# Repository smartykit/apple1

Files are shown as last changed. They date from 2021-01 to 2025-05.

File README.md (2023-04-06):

# SmartyKit One Apple-1 compatible computer repo structure

SmartyKit One Apple-1 compatible computer's drivers and software (http://www.smartykit.io/):
* **Controllers drivers** – drivers for all used controllers (Video, Keyboard & Hi-Res Video)
    - *Keyboard driver* uses Arduino PS2KeyAdvanced library.
    - *Video driver* uses Arduino custom 2.8" TFT screen driver (based on Adafruit driver) and TV Terminal library.
    - *Hi-Res Video driver* uses library written by Grant Searle and Dave Curran
* **Garage ASCII art** – beautiful Steve Job's garage ASCII art by Adel Faure

* **ROM** – ROM chip firmwarwe source code (6502 assembler) & development configs (Makefile to build your own version of ROM using `ca65` 6502 assembler & config files to run the code in POM1 emulator)

* **POM1 software emulator** – Apple-1 software emulator by Verhille Arnaud to test SmartyKit ROM code before burning firmare 

SmartyKit 1 assembly

# Highlights

## SmartyKit One's loading splash screen ASCII art
Steve Job's garage ASCII art by Adel Faure:

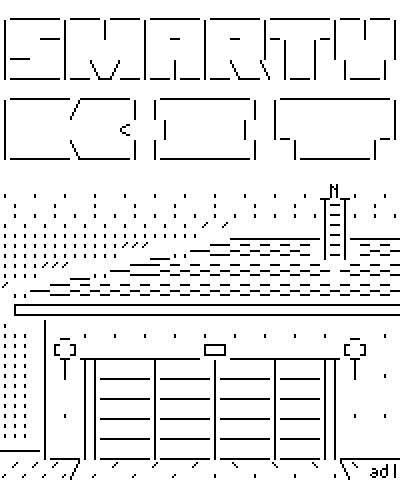
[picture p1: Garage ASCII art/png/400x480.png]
Steve Job's Garage


## SmartyKit One's ROM to run on POM1 Software Emulator 
POM 1 cross-platform emulator by Verhille Arnaud to test SmartyKit One ROM with software.

Video to-do (https://youtu.be/rniZDdS6toI)

## SmartyKit One's ROM development console
Easy-to-use development tool to write your own software for SmartyKLit One (you need just run make in your Terminal) and learn how ROM is organized.

Here is an example:
```bash
SERGEYs-MacBook:ROM_development spanarin$ make
SmartyKit 1: 6502 assembler & C-compiler to ROM (.bin)
Assembling and linking...
ca65 -l ROM_listing.asm SmartyKit1_ROM.asm
ld65 -m ROM.map -o SmartyKit1_ROM.bin SmartyKit1_ROM.o -C apple1.cfg
ld65 -o SmartyKit1_ROM_symon.bin SmartyKit1_ROM.o -C symon.cfg
SERGEYs-MacBook:ROM_development spanarin$
```

## SmartyKit One's 8x8 Pixel Art online tool for program at $FC00 in ROM (FC00R command)
You could draw your own pixel art using our online tool (https://smartykit.github.io/pixelart-project/), get the code for this image and load this code it to SmartyKit (or emulator) memory using command:
```
1111: 3C 42 A5 81 A5 99 42 3C (Return)
FC00R (Return)
```

## SmartyKit One's plates for breadboards

PCB version (black) and Wooden version (file for wood laser cutter: [download](https://github.com/smartykit/apple1/blob/01ea2ec54a94a7a31ee613f007602f0c08cb13ae/SmartyKit-Plate-for-breadboards(laser-cut).cdr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))

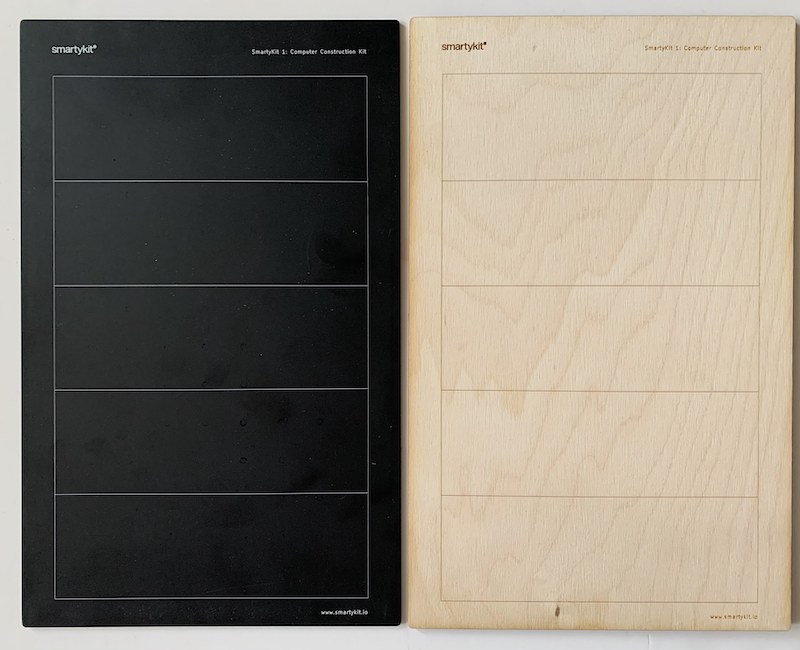
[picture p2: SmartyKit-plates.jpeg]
SmartyKit Plates


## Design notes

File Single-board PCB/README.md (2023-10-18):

# SmartyKit One, Apple-1 compatible computer's Single-board PCB gerbers

SmartyKit One (http://www.smartykit.io/), Apple-1 compatible computer's PCB production files:
* Gerbers with SMD (LED) pick&place files
* Schematics
* Assembly Drawing
* 3D Preview

These particular files were successfully used with JLCPCB.

This board is quite popular having almost 1 million views on TikTok: https://vt.tiktok.com/ZSN6fEfT1/

Short demo on how it works: https://youtube.com/shorts/yasQL7dERKI?si=belrGXeBrC0KbUY7

Then you can decorate your office or WFH study in a geeky way: https://www.instagram.com/p/CnwZLHJIJ2m/?igshid=MzRlODBiNWFlZA==

SmartyKit Discord community could be helpful during the build. 

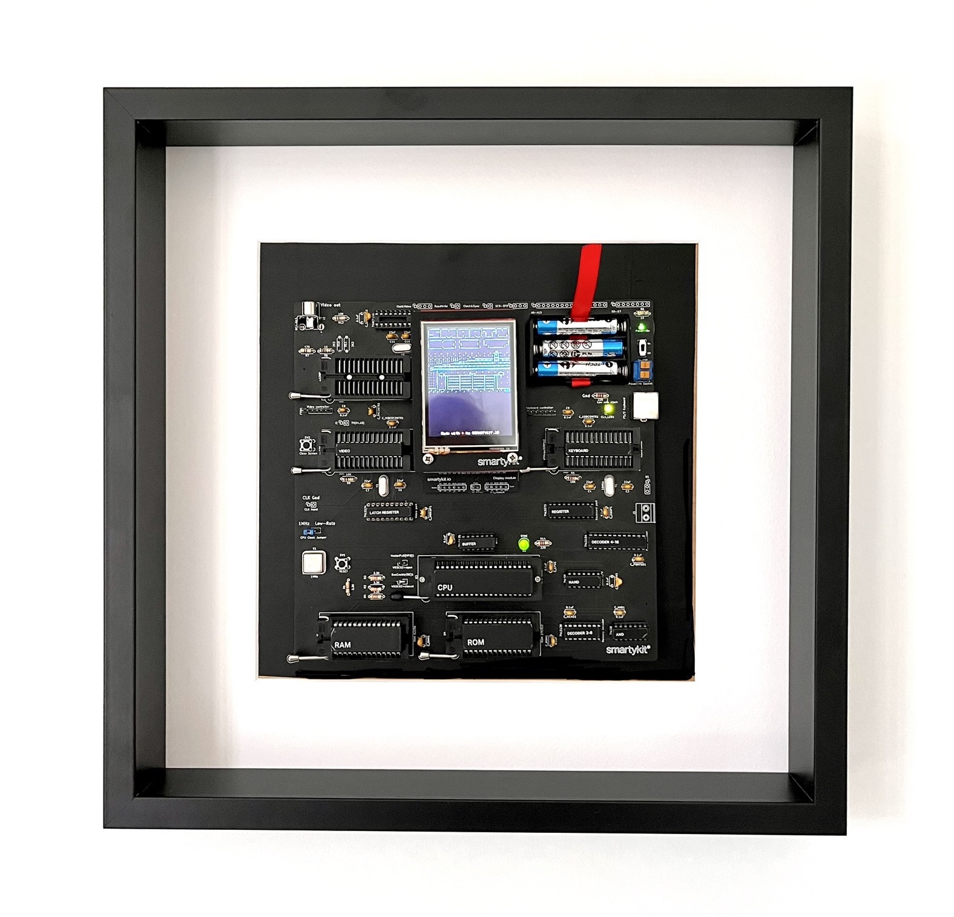
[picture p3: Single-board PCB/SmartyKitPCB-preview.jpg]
SmartyKit One PCB Preview


## Video instruction on ordering from JLCPCB

Watch video instruction on ordering from JLCPCB (https://www.youtube.com/watch?v=eLBNkHj5aZs)

## LED part number

For Power-On LED in 0603 package used – Everlight Elec, Part# 19-217/GHC-YR1S2/3T.

[JLCPCB Part# C72043](https://jlcpcb.com/partdetail/EverlightElec-19_217_GHC_YR1S23T/C72043)

## Questions?

You could contact Sergey (sergey@smartykit.io) or reach us on X (Twitter) ([@SmartyKitE](https://www.twitter.com/SmartyKitE)).

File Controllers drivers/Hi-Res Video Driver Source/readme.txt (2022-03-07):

To use this library you need an additional ATMega328P to act as a video processor, and a 74HCT166 shift register to generate the video bit stream.

The video processor hex file needs to be programmed into an ATMega328P with the following fuses set:
E6 D9 FF

In avrdude that is: (change the com port as appropriate)

avrdude -P COM3 -b 19200 -c avrisp -p m328p -n
avrdude -P COM3 -b 19200 -c avrisp -p m328p -U lfuse:w:0xe6:m
avrdude -P COM3 -b 19200 -c avrisp -p m328p -U hfuse:w:0xd9:m
avrdude -P COM3 -b 19200 -c avrisp -p m328p -U efuse:w:0xff:m
avrdude -P COM3 -b 19200 -c avrisp -p m328p -U flash:w:SBCVideo.hex

The video processor code is written by Grant Searle, based on code by Daryl Rictor.

Their pages are as follows:

http://searle.x10host.com/MonitorKeyboard/index.html
http://sbc.rictor.org/vid3.html

80x25 Terminal library by Dave Curran, based on code from the above. For more info see:

http://blog.tynemouthsoftware.co.uk/2013/09/arduino-80x25-tv-video-output-library.html
http://blog.tynemouthsoftware.co.uk/2013/09/arduino-80x25-tv-video-output-library_15.html

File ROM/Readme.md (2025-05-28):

## SmartyKit 1 Memory Map – ROM and RAM

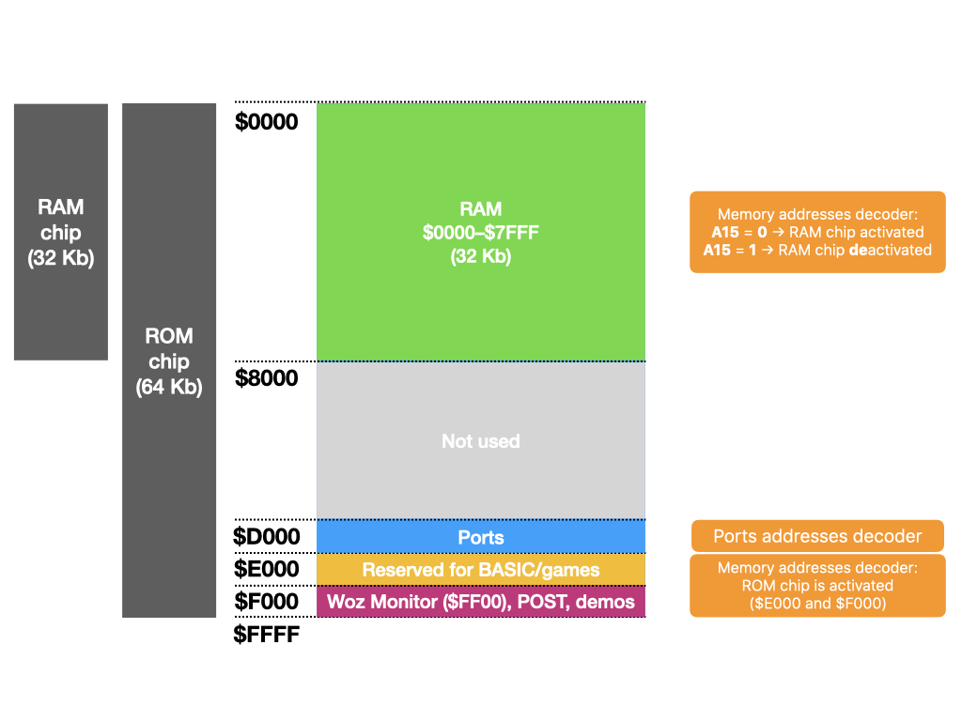
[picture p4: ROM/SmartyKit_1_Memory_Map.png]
SmartyKit 1 Memory Map


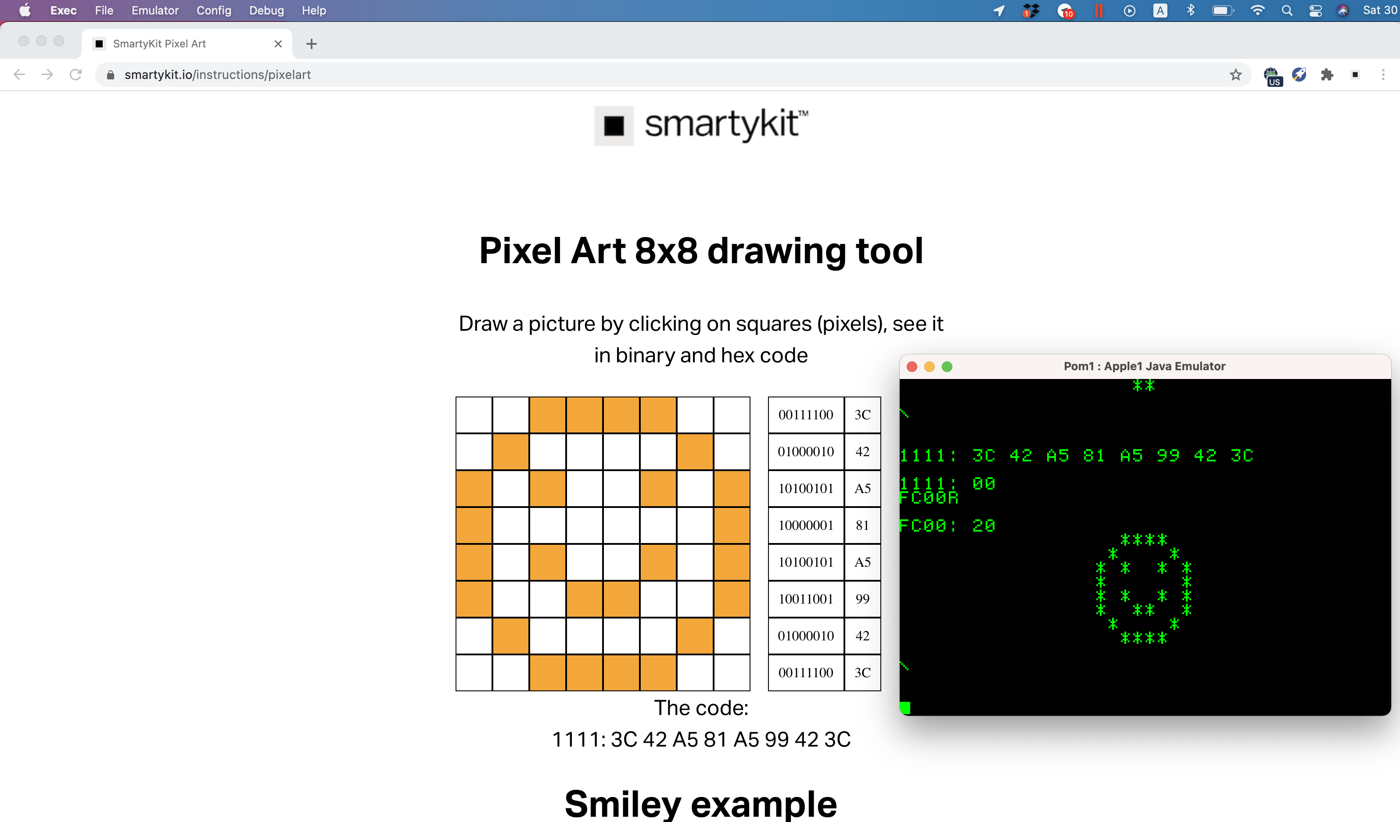
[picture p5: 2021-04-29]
SmartyKit Pixel Art example.png

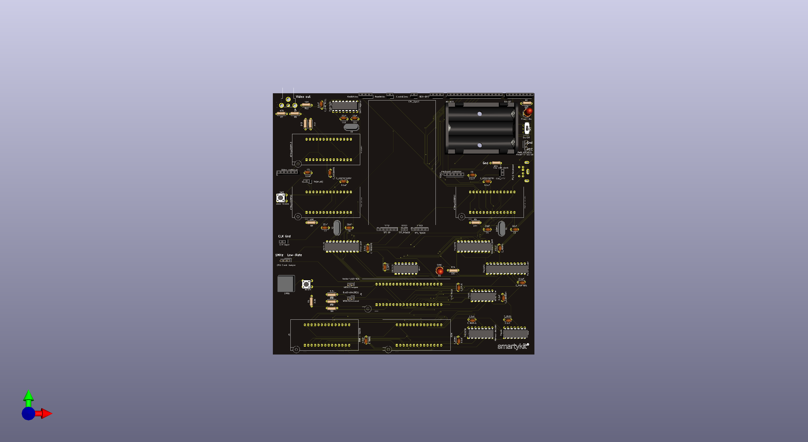
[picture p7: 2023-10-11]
Single-board PCB/SmartyKitPCB-3D-preview.png

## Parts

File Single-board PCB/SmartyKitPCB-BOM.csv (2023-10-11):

Comment | Designator | Footprint | LCSC Part #
NAND R/W quad 2-input NAND gate | 74LS0 | DIP-14_W7.62mm
AND Quad And2 | 74LS8 | DIP-14_W7.62mm
BIT7 Quad buffer 3-State outputs | 74LS125 | DIP-14_W7.62mm
Memory decoder Decoder 3 to 8 active low outputs | 74LS138 | DIP-16_W7.62mm
Ports decoder Decoder 4 to 16 | 74LS154 | DIP-24_W7.62mm
Keyboard port 8-bit Latch 3-state outputs | 74LS573 | DIP-20_W7.62mm
Video port 8-bit Register, 3-state outputs | 74LS574 | DIP-20_W7.62mm
A0-A15 Generic connector, single row, 01x16, script generated (kicad-library-utils/schlib/autogen/connector/) | AddressBus1 | PinSocket_1x16_P2.54mm_Vertical
5V Multiple-cell battery | BT1 | BatteryHolder_Keystone_2479_3xAAA
W65C02=closed Jumper, 2-pole, closed/bridged | BusEnable(BE)1 | PinHeader_1x02_P2.54mm_Vertical
0.1uF Unpolarized capacitor, small symbol | C1,C2,C5,C8,C9,C12,C13,C14,C15,C16,C17,C18,C19,C20,C21,C22 | C_Disc_D5.0mm_W2.5mm_P5.00mm
22pF Unpolarized capacitor, small symbol | C3,C4,C6,C7,C10,C11 | C_Disc_D5.0mm_W2.5mm_P5.00mm
CLK input Generic connector, single row, 01x02, script generated (kicad-library-utils/schlib/autogen/connector/) | CLK_INPUT1 | PinSocket_1x02_P2.54mm_Vertical
CPU Clock Jumper Generic connector, single row, 01x03, script generated (kicad-library-utils/schlib/autogen/connector/) | CLK_JMP1 | PinHeader_1x03_P2.54mm_Vertical
Low rate clock Generic connector, single row, 01x02, script generated (kicad-library-utils/schlib/autogen/connector/) | CLK_LED1 | PinSocket_1x02_P2.54mm_Vertical
Clock&Sync Generic connector, single row, 01x02, script generated (kicad-library-utils/schlib/autogen/connector/) | CPU_Sync1 | PinSocket_1x02_P2.54mm_Vertical
Power-On Light emitting diode, small symbol | D1 | LED_D5.0mm
SYNC Light emitting diode, small symbol | D2 | LED_D5.0mm
D0-D7 Generic connector, single row, 01x08, script generated (kicad-library-utils/schlib/autogen/connector/) | DataBus1 | PinSocket_1x08_P2.54mm_Vertical
Video controller Generic connector, single row, 01x06, script generated (kicad-library-utils/schlib/autogen/connector/) | FTDI1 | PinSocket_1x06_P2.54mm_Vertical
Keyboard controller Generic connector, single row, 01x06, script generated (kicad-library-utils/schlib/autogen/connector/) | FTDI2 | PinSocket_1x06_P2.54mm_Vertical
TV(A4,A5) Generic connector, single row, 01x02, script generated (kicad-library-utils/schlib/autogen/connector/) | J1 | PinSocket_1x02_P2.54mm_Vertical
RCJ-013 | J2 | CUI_RCJ-013
Screw_Terminal_01x02 Generic screw terminal, single row, 01x02, script generated (kicad-library-utils/schlib/autogen/connector/) | J3 | TerminalBlock_Phoenix_MKDS-1,5-2_1x02_P5.00mm_Horizontal
$C0-$F0 Generic connector, single row, 01x04, script generated (kicad-library-utils/schlib/autogen/connector/) | MemDecoder1 | PinSocket_1x04_P2.54mm_Vertical
PS/2 Keyboard | P1 | Connector_Mini-DIN_Female_6Pin_2rows
Kbd&Video Generic connector, single row, 01x04, script generated (kicad-library-utils/schlib/autogen/connector/) | PortsDecoder1 | PinSocket_1x04_P2.54mm_Vertical
Power-In Socket Generic connector, single row, 01x03, script generated (kicad-library-utils/schlib/autogen/connector/) | PWR_SOCKET1 | PinHeader_1x03_P2.54mm_Vertical
3.3K Resistor | R1,R2,R3,R4 | R_Axial_DIN0207_L6.3mm_D2.5mm_P7.62mm_Horizontal
10K Resistor, small symbol | R5,R9,R12 | R_Axial_DIN0207_L6.3mm_D2.5mm_P7.62mm_Horizontal
1K Resistor, small symbol | R6,R8 | R_Axial_DIN0207_L6.3mm_D2.5mm_P7.62mm_Horizontal
470 Resistor, small symbol | R7 | R_Axial_DIN0207_L6.3mm_D2.5mm_P7.62mm_Horizontal
2K2 Resistor, small symbol | R10,R11 | R_Axial_DIN0207_L6.3mm_D2.5mm_P7.62mm_Horizontal
220 Resistor, small symbol | R13,R14 | R_Axial_DIN0207_L6.3mm_D2.5mm_P7.62mm_Horizontal
ReadWrite Generic connector, single row, 01x02, script generated (kicad-library-utils/schlib/autogen/connector/) | ReadWrite1 | PinSocket_1x02_P2.54mm_Vertical
RESET Push button switch, generic, separate symbols, four pins | SW1 | SW_PUSH_6mm
Clear Screen Push button switch, generic, separate symbols, four pins | SW2 | SW_PUSH_6mm
On/Off Single Pole Single Throw (SPST) switch | SW3 | SW_CuK_JS202011CQN_DPDT_Straight
TFT SPI Generic connector, single row, 01x06, script generated (kicad-library-utils/schlib/autogen/connector/) | TFTS1 | PinSocket_1x06_P2.54mm_Vertical
TFT_POWER Generic connector, single row, 01x02, script generated (kicad-library-utils/schlib/autogen/connector/) | TFTS2 | PinSocket_1x02_P2.54mm_Vertical
TFT_TOUCH Generic connector, single row, 01x05, script generated (kicad-library-utils/schlib/autogen/connector/) | TFTS3 | PinSocket_1x05_P2.54mm_Vertical
L7805 Positive 1.5A 35V Linear Regulator, Fixed Output 5V, TO-220/TO-263/TO-252 | U1 | PinSocket_1x03_P2.54mm_Vertical
RAM 62256 256K (32K x 8) Static RAM, 70ns, DIP-28 | U2 | DIP_Socket-28_W11.9_W12.7_W15.24_W17.78_W18.5_3M_228-1277-00-0602J
CPU 6502 W65C02S 8-bit CMOS General Purpose Microprocessor, DIP-40 | U3 | DIP_Socket-40_W11.9_W12.7_W15.24_W17.78_W18.5_3M_240-1280-00-0602J
ROM 27C512 OTP EPROM 512 KiBit | U4 | DIP_Socket-28_W11.9_W12.7_W15.24_W17.78_W18.5_3M_228-1277-00-0602J

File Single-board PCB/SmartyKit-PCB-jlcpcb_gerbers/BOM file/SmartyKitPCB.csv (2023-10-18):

Comment | Designator | Footprint | LCSC Part #
Power-On Light emitting diode, small symbol | D1 | LED_D5.0mm | C72043

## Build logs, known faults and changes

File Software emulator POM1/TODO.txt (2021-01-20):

TODO :

*Graphisme
Marges
SpeedUp pour l'affichage des characteres sous
forme d'image et le masquage lors de update()
Icones pour Pom1

*Core
Faire un debugger
Fichier config pour le clavier

*Applet
Faire marcher Pom1Applet.java

*Misc
Ecrire quelques jeux
2ksa

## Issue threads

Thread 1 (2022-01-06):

Kicad schematic seems to depend on a missing modules cache file

sparky62, 2022-01-06:
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

Kicad seems to depend on a missing modules cache file

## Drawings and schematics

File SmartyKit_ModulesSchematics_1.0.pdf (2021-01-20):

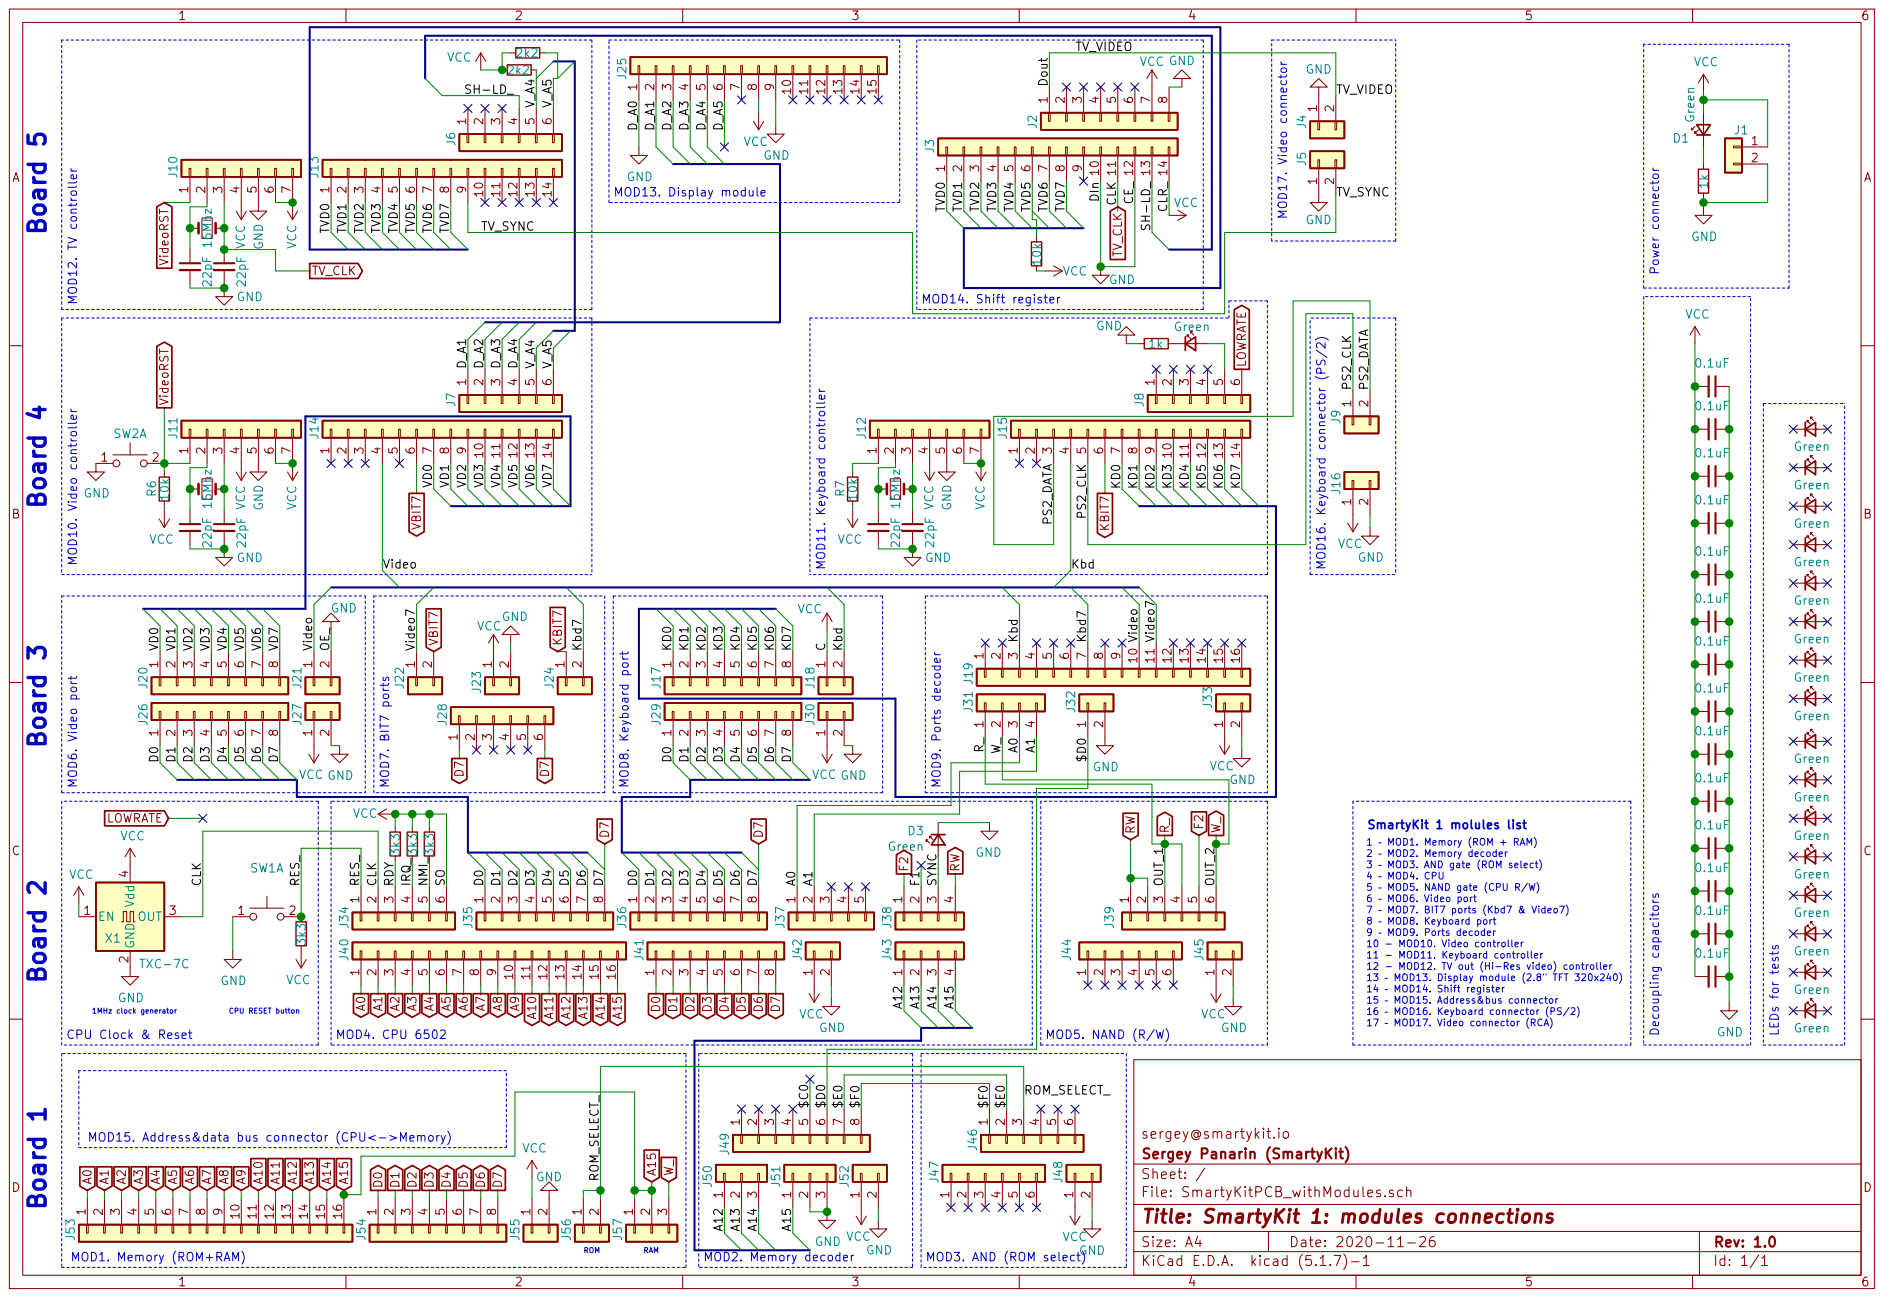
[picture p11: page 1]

6 J44 VCCGND A3 D7 A2A4 F2RW D0 A5A6 A1A2A3 A7 D3 D7 TV_CLK VBIT7 LOWRATE A0A1 TV_CLK A0 D2 D4 D6 D7 VideoRST VideoRST D1 D5 D1 A14 A15 VBIT7 KBIT7 A5A6A7A8 D0 D7 A15 W_ A4 A8D2 A9A10 A11 D3 D4 D5 D6 D7 D7 A15 RWR_ A11 A12 A13 F2 A14 A10 A12 A13A9

sergey@smartykit.io GND

7 J11 VCC GND VCCR6 10k VCC 22pF 22pF VCC

2 J45Green Green Green Green Green

5 MOD5. NAND gate (CPU R/W) 6 MOD6. Video port 7 MOD7. BIT7 ports (Kbd7 & Video7) 8 MOD8. Keyboard port 9 MOD9. Ports decoder 10 - MOD10. Video controller 11 - MOD11. Keyboard controller 12 - MOD12. TV out (Hi-Res video) controller 13 MOD13. Display module (2.8" TFT 320x240) 14 MOD14. Shift register 15 MOD15. Address&bus connector 16 MOD16. Keyboard connector (PS/2) 17 MOD17. Video connector (RCA) SmartyKit 1 molules list
1 MOD1. Memory (ROM + RAM) 2 MOD2. Memory decoder 3 MOD3. AND gate (ROM select) 4 MOD4. CPU

File: SmartyKitPCB_withModules.sch Sheet: / Sergey Panarin (SmartyKit)

Id: 1/1 Title: SmartyKit 1: modules connections

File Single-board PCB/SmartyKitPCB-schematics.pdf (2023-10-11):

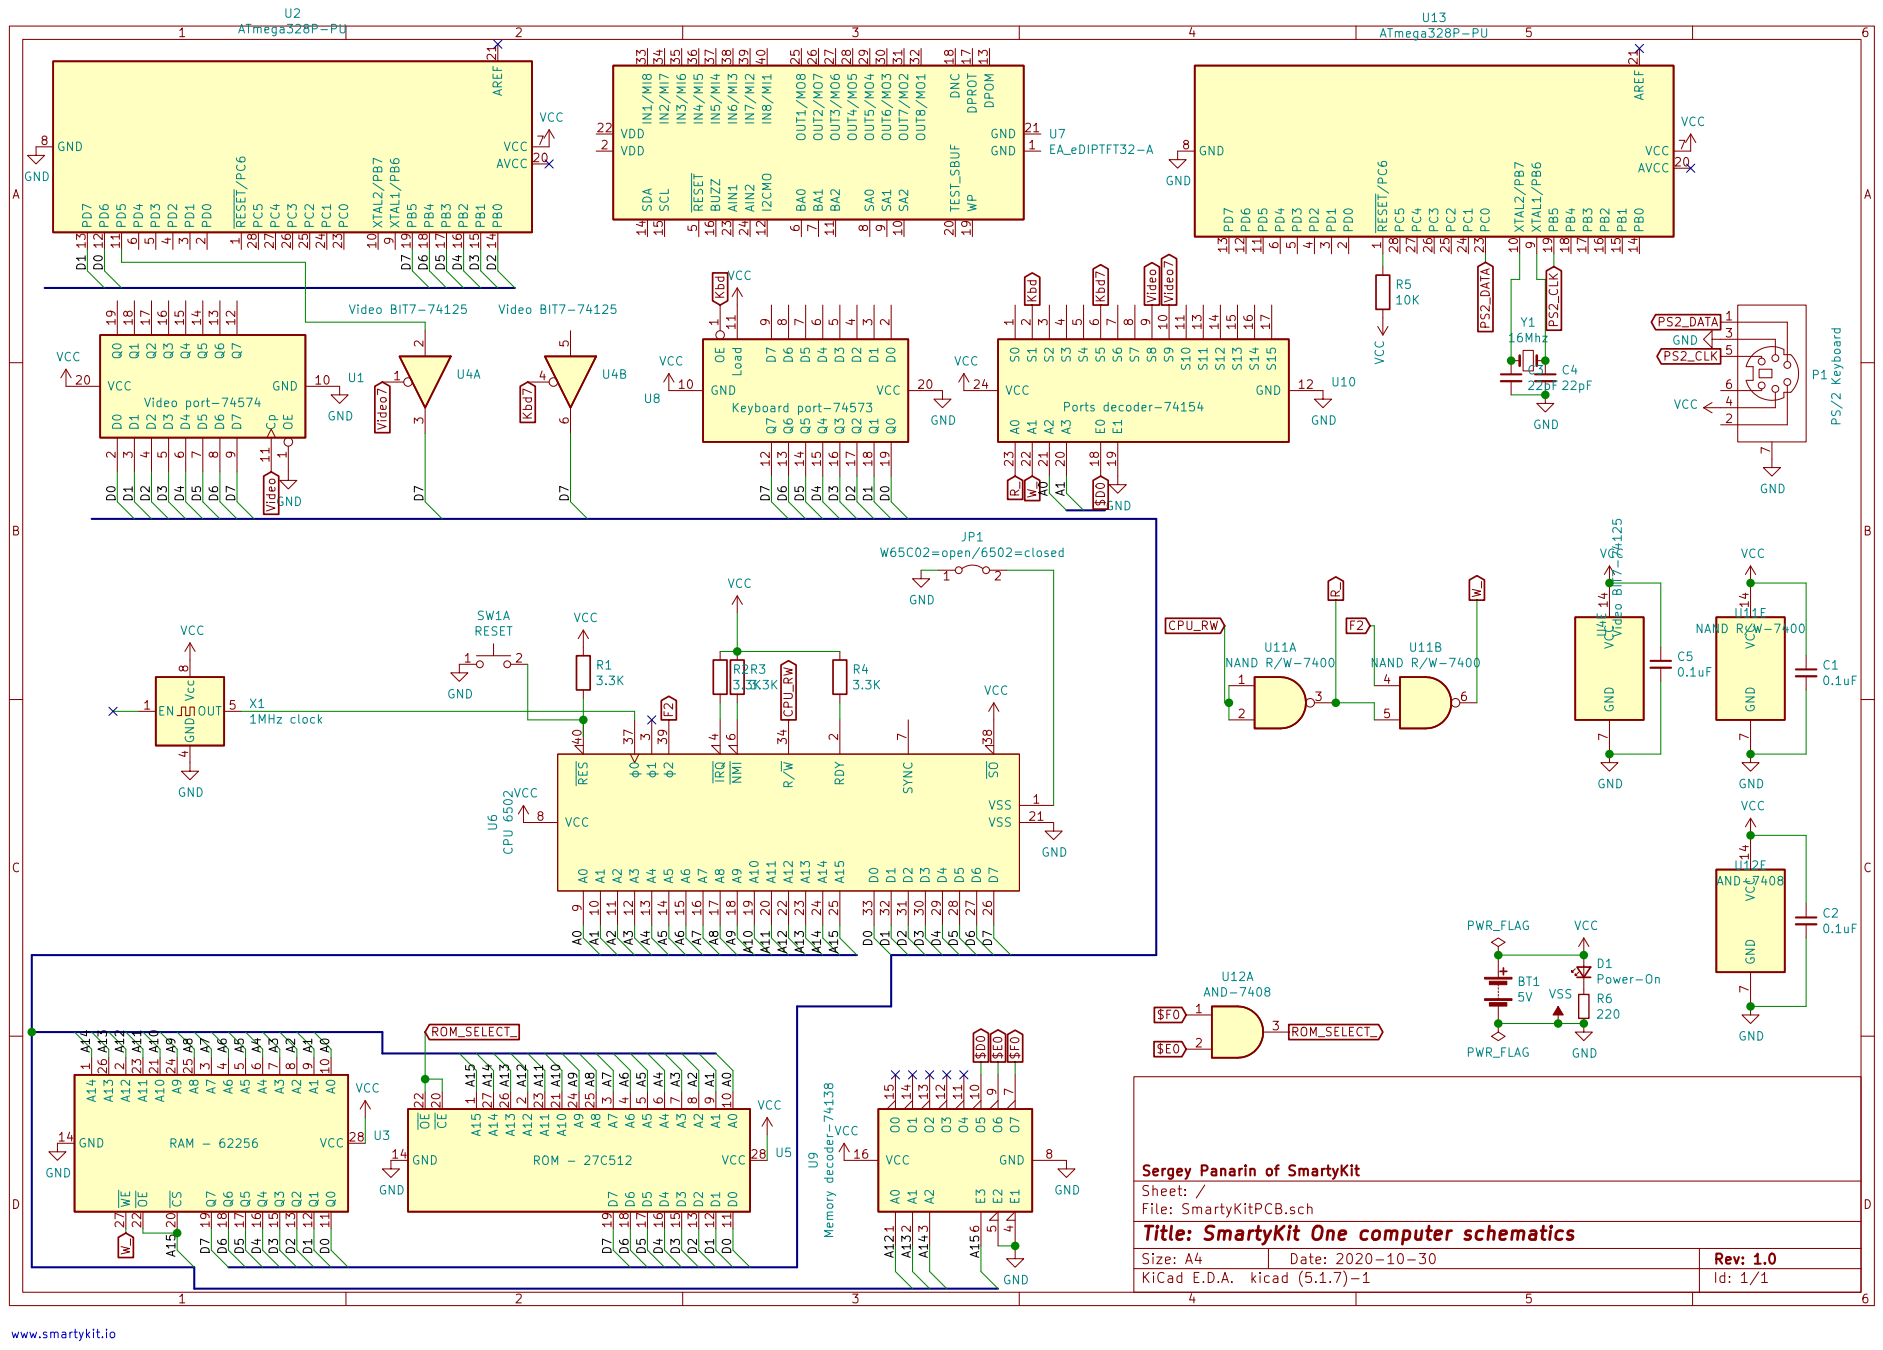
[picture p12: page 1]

9 U13 ATmega328P-PU GND 1 VDD 2 RESET

9 SA2 10 TEST_SBUF 20 OUT6/MO3 30 IN8/MI1 40 BA2 11 GND OUT7/MO2 21 31 I2CMO 12 VDD 22 OUT8/MO1 32 DPOM 13 AIN1 23 IN1/MI8 33 SDA 14 AIN2 24 IN2/MI7 34 SCL 15 OUT1/MO8 25 IN3/MI6 35 BUZZ 16 OUT2/MO7 26 IN4/MI5 36 DPROT 17 OUT3/MO6 27 IN5/MI4 37 DNC 18 OUT4/MO5 28 IN6/MI3 38 WP 19 OUT5/MO4 29 IN7/MI2 39 U7EA_eDIPTFT32-A OE

9 U8 Keyboard port-74573 GND GND

7 U11E NAND R/W-7400 VCC GNDVCC 14 GND

9 A0 10 CE 20 D0 11 A10 21 D1 12 OE 22 D2 13 A11 23 GND 14 A9 24 D3 15 A8 25 D4 16 A13 26 D5 17 A14 27 D6 18 VCC 28 D7 19 U5 ROM - 27C512

File: SmartyKitPCB.sch Sheet: / Sergey Panarin of SmartyKit

Id: 1/1 Title: SmartyKit One computer schematics

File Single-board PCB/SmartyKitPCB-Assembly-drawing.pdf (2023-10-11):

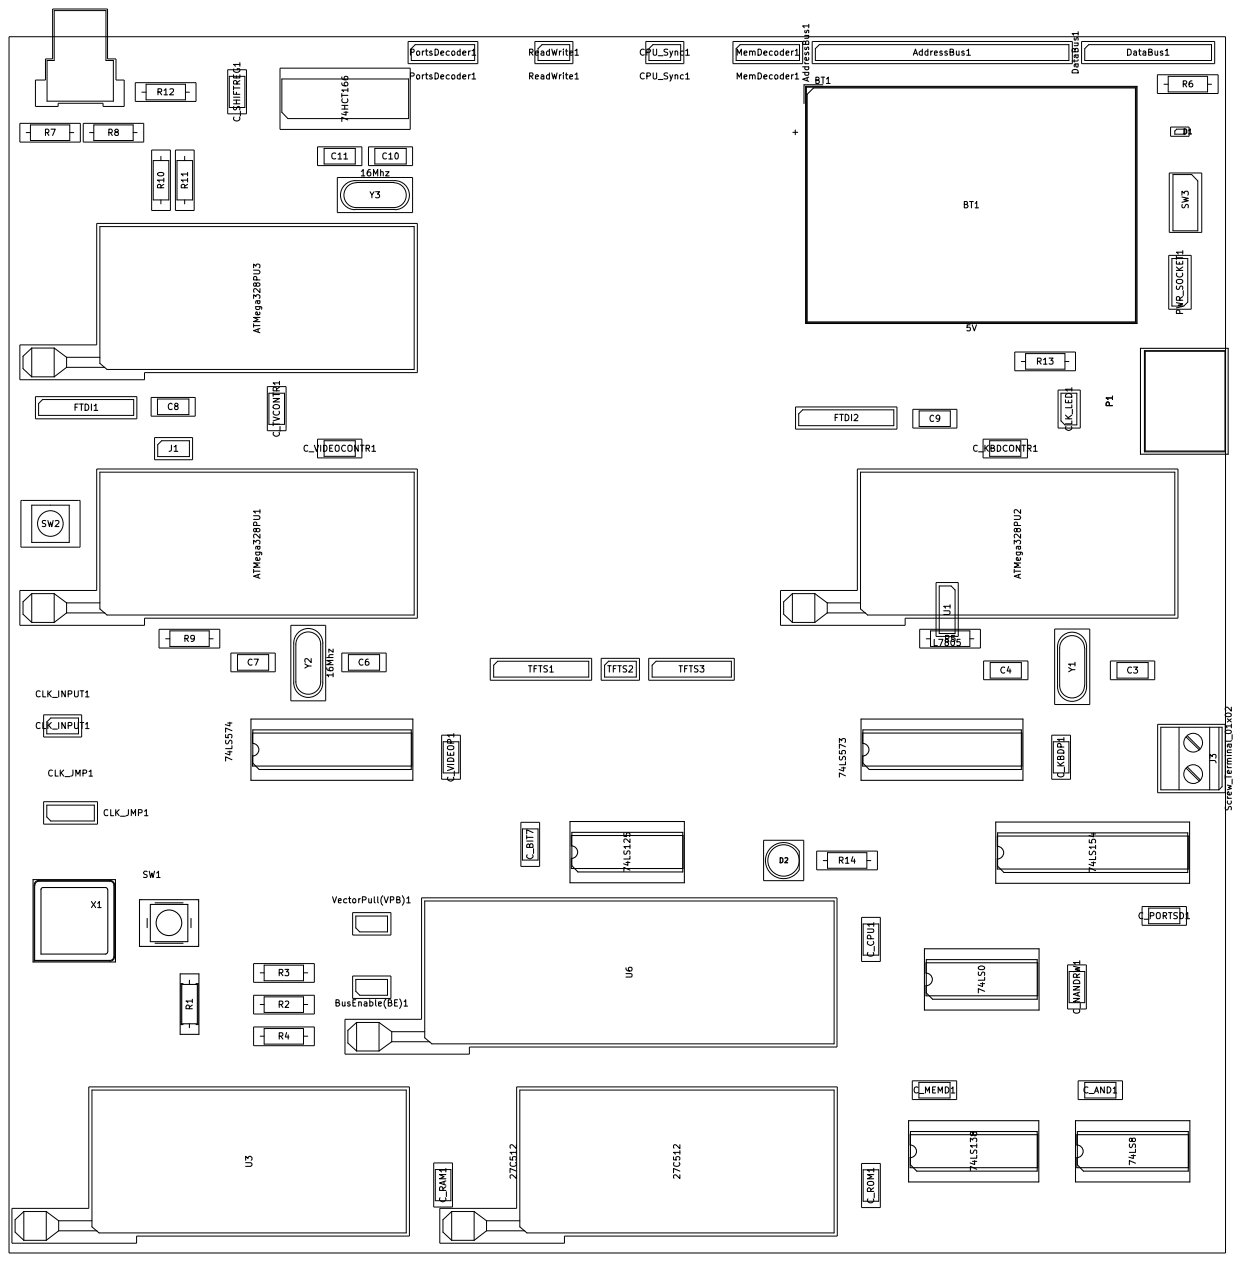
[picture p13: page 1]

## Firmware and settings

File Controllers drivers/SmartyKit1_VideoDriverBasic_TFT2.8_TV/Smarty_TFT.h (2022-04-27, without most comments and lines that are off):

#define _SMARTYKIT_DISPLAY_DRIVER_IL9341H_
#include <SPI.h>
#define ILI9341_TFTWIDTH 240  ///< ILI9341 max TFT width
#define ILI9341_TFTHEIGHT 320 ///< ILI9341 max TFT height
#define TFT_TFTwidth 320
#define TFT_TFTheight 240
#define SCREEN_COLS 40
#define SCREEN_ROWS 24
#define LINE_WIDTH 6
#define LINE_HEIGHT 8
#define SCREEN_WIDTH SCREEN_COLS*LINE_WIDTH
#define SCREEN_HEIGHT SCREEN_ROWS*LINE_HEIGHT
#define MARGIN_TOP 3*LINE_HEIGHT
#define MARGIN_BOTTOM 3*LINE_HEIGHT
#define MARGIN_LEFT (TFT_TFTwidth - SCREEN_COLS*LINE_WIDTH)/2
#define MARGIN_RIGHT (TFT_TFTwidth - SCREEN_COLS*LINE_WIDTH)/2
#define SCREEN_TOP MARGIN_TOP
#define SCREEN_BOTTOM (TFT_TFTheight - MARGIN_BOTTOM)
#define SCREEN_LEFT MARGIN_LEFT
#define SCREEN_RIGHT (TFT_TFTwidth - MARGIN_RIGHT)
#define SCREEN_RECT_MARGIN 3
#define ILI9341_NOP 0x00     ///< No-op register
#define ILI9341_SWRESET 0x01 ///< Software reset register
#define ILI9341_RDDID 0x04   ///< Read display identification information
#define ILI9341_RDDST 0x09   ///< Read Display Status
#define ILI9341_SLPIN 0x10  ///< Enter Sleep Mode
#define ILI9341_SLPOUT 0x11 ///< Sleep Out
#define ILI9341_PTLON 0x12  ///< Partial Mode ON
#define ILI9341_NORON 0x13  ///< Normal Display Mode ON
#define ILI9341_RDMODE 0x0A     ///< Read Display Power Mode
#define ILI9341_RDMADCTL 0x0B   ///< Read Display MADCTL
#define ILI9341_RDPIXFMT 0x0C   ///< Read Display Pixel Format
#define ILI9341_RDIMGFMT 0x0D   ///< Read Display Image Format
#define ILI9341_RDSELFDIAG 0x0F ///< Read Display Self-Diagnostic Result
#define ILI9341_INVOFF 0x20   ///< Display Inversion OFF
#define ILI9341_INVON 0x21    ///< Display Inversion ON
#define ILI9341_GAMMASET 0x26 ///< Gamma Set
#define ILI9341_DISPOFF 0x28  ///< Display OFF
#define ILI9341_DISPON 0x29   ///< Display ON
#define ILI9341_CASET 0x2A ///< Column Address Set
#define ILI9341_PASET 0x2B ///< Page Address Set
#define ILI9341_RAMWR 0x2C ///< Memory Write
#define ILI9341_RAMRD 0x2E ///< Memory Read
#define ILI9341_PTLAR 0x30    ///< Partial Area
#define ILI9341_VSCRDEF 0x33  ///< Vertical Scrolling Definition
#define ILI9341_MADCTL 0x36   ///< Memory Access Control
#define ILI9341_VSCRSADD 0x37 ///< Vertical Scrolling Start Address
#define ILI9341_PIXFMT 0x3A   ///< COLMOD: Pixel Format Set
#define ILI9341_FRMCTR1                                                        \
  0xB1 ///< Frame Rate Control (In Normal Mode/Full Colors)
#define ILI9341_FRMCTR2 0xB2 ///< Frame Rate Control (In Idle Mode/8 colors)
#define ILI9341_FRMCTR3                                                        \
  0xB3 ///< Frame Rate control (In Partial Mode/Full Colors)
#define ILI9341_INVCTR 0xB4  ///< Display Inversion Control
#define ILI9341_DFUNCTR 0xB6 ///< Display Function Control
#define ILI9341_PWCTR1 0xC0 ///< Power Control 1
#define ILI9341_PWCTR2 0xC1 ///< Power Control 2
#define ILI9341_PWCTR3 0xC2 ///< Power Control 3
#define ILI9341_PWCTR4 0xC3 ///< Power Control 4
#define ILI9341_PWCTR5 0xC4 ///< Power Control 5
#define ILI9341_VMCTR1 0xC5 ///< VCOM Control 1
#define ILI9341_VMCTR2 0xC7 ///< VCOM Control 2
#define ILI9341_RDID1 0xDA ///< Read ID 1
#define ILI9341_RDID2 0xDB ///< Read ID 2
#define ILI9341_RDID3 0xDC ///< Read ID 3
#define ILI9341_RDID4 0xDD ///< Read ID 4
#define ILI9341_GMCTRP1 0xE0 ///< Positive Gamma Correction
#define ILI9341_GMCTRN1 0xE1 ///< Negative Gamma Correction
#define MADCTL_MY 0x80  ///< Bottom to top
#define MADCTL_MX 0x40  ///< Right to left
#define MADCTL_MV 0x20  ///< Reverse Mode
#define MADCTL_NOTMV 0x00  ///< Reverse Mode
#define MADCTL_ML 0x10  ///< LCD refresh Bottom to top
#define MADCTL_RGB 0x00 ///< Red-Green-Blue pixel order
#define MADCTL_BGR 0x08 ///< Blue-Green-Red pixel order
#define MADCTL_MH 0x04  ///< LCD refresh right to left
#define ILI9341_BLACK 0x0000       ///<   0,   0,   0
#define ILI9341_NAVY 0x000F        ///<   0,   0, 123
#define ILI9341_DARKGREEN 0x03E0   ///<   0, 125,   0
#define ILI9341_DARKCYAN 0x03EF    ///<   0, 125, 123
#define ILI9341_MAROON 0x7800      ///< 123,   0,   0
#define ILI9341_PURPLE 0x780F      ///< 123,   0, 123
#define ILI9341_OLIVE 0x7BE0       ///< 123, 125,   0
#define ILI9341_LIGHTGREY 0xC618   ///< 198, 195, 198
#define ILI9341_DARKGREY 0x7BEF    ///< 123, 125, 123
#define ILI9341_BLUE 0x001F        ///<   0,   0, 255
#define ILI9341_GREEN 0x07E0       ///<   0, 255,   0
#define ILI9341_CYAN 0x07FF        ///<   0, 255, 255
#define ILI9341_RED 0xF800         ///< 255,   0,   0
#define ILI9341_MAGENTA 0xF81F     ///< 255,   0, 255
#define ILI9341_YELLOW 0xFFE0      ///< 255, 255,   0
#define ILI9341_WHITE 0xFFFF       ///< 255, 255, 255
#define ILI9341_ORANGE 0xFD20      ///< 255, 165,   0
#define ILI9341_GREENYELLOW 0xAFE5 ///< 173, 255,  41
#define ILI9341_PINK 0xFC18        ///< 255, 130, 198
#define TFT_HARD_SPI 0 ///< Display interface = hardware SPI
#define TFT_SOFT_SPI 1 ///< Display interface = software SPI
#define TFT_PORTRAIT 1
#define TFT_LANDSCAPE 0
#define CURSOR_RELATIVE 1
#define CURSOR_ABSOLUTE 0
#define SCREEN_FULL_SCREEN 0
#define SCREEN_CLIPPED 1
#if defined(__AVR__)
#define DEFAULT_SPI_FREQ 2000000 ///< Hardware SPI default speed
#else
#define DEFAULT_SPI_FREQ 4000000L ///< Hardware SPI default speed
#endif
#if defined(__AVR__)
#define AVR_WRITESPI(x) for (SPDR = (x); (!(SPSR & _BV(SPIF)));)
#endif
static const uint8_t PROGMEM initcmd[] = {
  0xEF, 3, 0x03, 0x80, 0x02,
  0xCF, 3, 0x00, 0xC1, 0x30,             //Power control B (CFh)
  0xED, 4, 0x64, 0x03, 0x12, 0x81,       //Power on sequence control (EDh)
  0xE8, 3, 0x85, 0x00, 0x78,             //Driver timing control A (E8h) 0xE8, 3, 0x85, 0x00, 0x78,
  0xCB, 5, 0x39, 0x2C, 0x00, 0x34, 0x02, //Power control A (CBh)
  0xF7, 1, 0x20,                         //Pump ratio control (F7h)
  0xEA, 2, 0x00, 0x00,                   //Driver timing control B (EAh) 0xEA, 2, 0x00, 0x00,
  ILI9341_PWCTR1  , 1, 0x23,             // Power control VRH[5:0]
  ILI9341_PWCTR2  , 1, 0x10,             // Power control SAP[2:0];BT[3:0]
  ILI9341_VMCTR1  , 2, 0x3e, 0x28,       // VCM control
  ILI9341_VMCTR2  , 1, 0x86,             // VCM control2
  ILI9341_MADCTL  , 1, 0x48,             // Memory Access Control
  ILI9341_VSCRSADD, 1, 0x00,             // Vertical scroll zero
  ILI9341_PIXFMT  , 1, 0x55,
  ILI9341_FRMCTR1 , 2, 0x00, 0x18,
  ILI9341_DFUNCTR , 3, 0x08, 0x82, 0x27, // Display Function Control
  0xF2, 1, 0x00,                         // 3Gamma Function Disable
  ILI9341_GAMMASET , 1, 0x01,             // Gamma curve selected
  ILI9341_GMCTRP1 , 15, 0x0F, 0x31, 0x2B, 0x0C, 0x0E, 0x08, // Set Gamma
    0x4E, 0xF1, 0x37, 0x07, 0x10, 0x03, 0x0E, 0x09, 0x00,
  ILI9341_GMCTRN1 , 15, 0x00, 0x0E, 0x14, 0x03, 0x11, 0x07, // Set Gamma
    0x31, 0xC1, 0x48, 0x08, 0x0F, 0x0C, 0x31, 0x36, 0x0F,
  ILI9341_SLPOUT  , 0x80,                // Exit Sleep
  ILI9341_DISPON  , 0x80,                // Display on
  0x00                                   // End of list
};
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

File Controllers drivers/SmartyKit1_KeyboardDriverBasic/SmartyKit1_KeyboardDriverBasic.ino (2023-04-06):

/*  SmartyKit 1 - PS/2 keyboard driver v.1.2 (2023)
*  (with automatic mode if no PS/2 keyboard is connected)
*  http://www.smartykit.io/
*  Copyright (C) 2020, Sergey Panarin <sergey@smartykit.io>
*
   This program is free software: you can redistribute it and/or modify
   it under the terms of the GNU General Public License as published by
   the Free Software Foundation, either version 3 of the License, or
   (at your option) any later version.
   This program is distributed in the hope that it will be useful,
   but WITHOUT ANY WARRANTY; without even the implied warranty of
   MERCHANTABILITY or FITNESS FOR A PARTICULAR PURPOSE.  See the
   GNU General Public License for more details.
   You should have received a copy of the GNU General Public License
   along with this program.  If not, see <https://www.gnu.org/licenses/>.
*/

#include "PS2KeyAdvanced.h"

// Keyboard Driver pins connections:
// D0 & D1 – reserved for Serial connection
// D2 –> PS/2 Socket Data pin
// D3 -> 4-16 ports decoder Kbd (2) out pin (signal is active when CPU reads Keyboatrd port)
// D4 -> PS/2 Socket Clk pin
// D5 -> Keyboard BIT7 pin output
// D6-D13 -> Keyboard data bus output (8 pins) to connect to Keyboard port (char code is transfered here)
// A4 -> Low-rate clock output for CPU CLK input
// A5 -> Low-rate clock output for indicating LED connection

#define PS2KEYBOARDCLOCK_PIN 2
#define KEYBOARD_RD_PIN 3
#define PS2KEYBOARD_DATA_PIN 4
#define KEYBOARD_BIT7_PIN 5

const int KeyboardPort[8] = {6, 7, 8, 9, 10, 11, 12, 13};

static boolean autoMode = false;        // run pre-set command or wait for user input from PS/2 keyboard
static boolean autoCommandSent = false; // run pre-set command only once after reboot of Keyboard controller

// low-rate clock for tests on A4-A5
#define LORATE_CLOCK_PIN A4
#define LORATE_CLOCK_LED_PIN A5

// 100 milliseconds = 10 times per second (10 Hz)
#define LORATE_CLOCK_PERIOD_MILLIS 100

// Uncomment any of following defines to include those mappings
// or comment to exclude
// #define GERMAN
// #define FRENCH
// #define SPANISH
// #define ITALIAN
// #define SPECIAL

/* UTF-8 single byte LATIN encodings
   128 to 159 (0x80 to 0x9F) are control characters application generated
   160 to 255 (0xA0 to 0XFF) are used depending on keymap tables
   These defines are used to insert them into correct tables */

/****************************************************************
  IMPORTANT NOTE EURO currency Symbol is NOT supported in UTF-8 single
  byte codings, as EURO symbol came after UTF-8 single byte codings
****************************************************************/
#define PS2_NO_BREAK_SPACE 160          // nbsp
#define PS2_INVERTED_EXCLAMATION 161    // ¡
#define PS2_CENT_SIGN 162               // ¢
#define PS2_POUND_SIGN 163              // £
#define PS2_CURRENCY_SIGN 164           // ¤
#define PS2_YEN_SIGN 165                // ¥
#define PS2_BROKEN_BAR 166              // ¦
#define PS2_SECTION_SIGN 167            // §
#define PS2_DIAERESIS 168               // ¨
#define PS2_COPYRIGHT_SIGN 169          // ©
#define PS2_FEMININE_ORDINAL 170        // ª
#define PS2_LEFT_DOUBLE_ANGLE_QUOTE 171 // «
#define PS2_NOT_SIGN 172                // ¬
#define PS2_HYPHEN 173
#define PS2_REGISTERED_SIGN 174          // ®
#define PS2_MACRON 175                   // ¯
#define PS2_DEGREE_SIGN 176              // °
#define PS2_PLUS_MINUS_SIGN 177          // ±
#define PS2_SUPERSCRIPT_TWO 178          // ²
#define PS2_SUPERSCRIPT_THREE 179        // ³
#define PS2_ACUTE_ACCENT 180             // ´
#define PS2_MICRO_SIGN 181               // µ
#define PS2_PILCROW_SIGN 182             // ¶
#define PS2_MIDDLE_DOT 183               // ·
#define PS2_CEDILLA 184                  // ¸
#define PS2_SUPERSCRIPT_ONE 185          // ¹
#define PS2_MASCULINE_ORDINAL 186        // º
#define PS2_RIGHT_DOUBLE_ANGLE_QUOTE 187 // »
#define PS2_FRACTION_ONE_QUARTER 188     // ¼
#define PS2_FRACTION_ONE_HALF 189        // ½
#define PS2_FRACTION_THREE_QUARTERS 190  // ¾
#define PS2_INVERTED_QUESTION_MARK 191   // ¿
#define PS2_A_GRAVE 192                  // À
#define PS2_A_ACUTE 193                  // Á
#define PS2_A_CIRCUMFLEX 194             // Â
#define PS2_A_TILDE 195                  // Ã
#define PS2_A_DIAERESIS 196              // Ä
#define PS2_A_RING_ABOVE 197             // Å
#define PS2_AE 198                       // Æ
#define PS2_C_CEDILLA 199                // Ç
#define PS2_E_GRAVE 200                  // È
#define PS2_E_ACUTE 201                  // É
#define PS2_E_CIRCUMFLEX 202             // Ê
#define PS2_E_DIAERESIS 203              // Ë
#define PS2_I_GRAVE 204                  // Ì
#define PS2_I_ACUTE 205                  // Í
#define PS2_I_CIRCUMFLEX 206             // Î
#define PS2_I_DIAERESIS 207              // Ï
#define PS2_ETH 208                      // Ð
#define PS2_N_TILDE 209                  // Ñ
#define PS2_O_GRAVE 210                  // Ò
#define PS2_O_ACUTE 211                  // Ó
#define PS2_O_CIRCUMFLEX 212             // Ô
#define PS2_O_TILDE 213                  // Õ
#define PS2_O_DIAERESIS 214              // Ö
#define PS2_MULTIPLICATION 215           // ×
#define PS2_O_STROKE 216                 // Ø
#define PS2_U_GRAVE 217                  // Ù
#define PS2_U_ACUTE 218                  // Ú
#define PS2_U_CIRCUMFLEX 219             // Û
#define PS2_U_DIAERESIS 220              // Ü
#define PS2_Y_ACUTE 221                  // Ý
#define PS2_THORN 222                    // Þ
#define PS2_SHARP_S 223                  // ß
#define PS2_a_GRAVE 224                  // à
#define PS2_a_ACUTE 225                  // á
#define PS2_a_CIRCUMFLEX 226             // â
#define PS2_a_TILDE 227                  // ã
#define PS2_a_DIAERESIS 228              // ä
#define PS2_a_RING_ABOVE 229             // å
#define PS2_ae 230                       // æ
#define PS2_c_CEDILLA 231                // ç
#define PS2_e_GRAVE 232                  // è
#define PS2_e_ACUTE 233                  // é
#define PS2_e_CIRCUMFLEX 234             // ê
#define PS2_e_DIAERESIS 235              // ë
#define PS2_i_GRAVE 236                  // ì
#define PS2_i_ACUTE 237                  // í
#define PS2_i_CIRCUMFLEX 238             // î
#define PS2_i_DIAERESIS 239              // ï
#define PS2_eth 240                      // ð
#define PS2_n_TILDE 241                  // ñ
#define PS2_o_GRAVE 242                  // ò
#define PS2_o_ACUTE 243                  // ó
#define PS2_o_CIRCUMFLEX 244             // ô
#define PS2_o_TILDE 245                  // õ
#define PS2_o_DIAERESIS 246              // ö
#define PS2_DIVISION 247                 // ÷
#define PS2_o_STROKE 248                 // ø
#define PS2_u_GRAVE 249                  // ù
#define PS2_u_ACUTE 250                  // ú
#define PS2_u_CIRCUMFLEX 251             // û
#define PS2_u_DIAERESIS 252              // ü
#define PS2_y_ACUTE 253                  // ý
#define PS2_thorn 254                    // þ
#define PS2_y_DIAERESIS 255              // ÿ

/* Public class definition */
class SmartyPS2KeyMap
{
public:
  /**
   * This constructor just sets the default key mapping to US. */
  SmartyPS2KeyMap();

  /**
   Pass in 2 character string for the ISO 2 letter country code in use
      For UK "UK" or "GB" are valid
      "US" is built-in default
   Returns 1 for done or 0 for not found.
   */
  uint8_t selectMap(char *);

  /**
   Return selected map as a string pointer (2 chars and terminator)    */
  const char *getMap(void);

  /**
   Pass in unsigned int returned from PS2KeyAdvanced
              Returns 0 for error
                      uint16_t for valid code
   */
  uint16_t remapKey(uint16_t);

  /**
    Returns uint8_t version of remapKey ONLY for standard ASCII/UTF-8 codes
    Invalid codes returned as 0
   */
  uint8_t remapKeyByte(uint16_t);
};

/* Standard ASCII/UTF-8 control Characters */
#define PS2_BACKSPACE 0x08
#define PS2_TAB 0x09
#define PS2_ENTER 0x0D
#define PS2_ESC 0x1B
#define PS2_DELETE 0x7F
#define PS2_SPACE 0x20

/* Standard ASCII control characters array */
/* in order of PS2_KEY_* values order is important */
const uint8_t _control_codes[] = {
    PS2_DELETE, PS2_ESC, PS2_BACKSPACE,
    PS2_TAB, PS2_ENTER, PS2_SPACE};

// convert codes based on SHIFT and not SHIFT only for base US-ASCII
const uint16_t _US_ASCII[][2] = {
    {PS2_SHIFT + PS2_KEY_1, '!'},
    {PS2_SHIFT + PS2_KEY_2, '@'},
    {PS2_SHIFT + PS2_KEY_3, '#'},
    {PS2_SHIFT + PS2_KEY_4, '$'},
    {PS2_SHIFT + PS2_KEY_5, '%'},
    {PS2_SHIFT + PS2_KEY_6, '^'},
    {PS2_SHIFT + PS2_KEY_7, '&'},
    {PS2_SHIFT + PS2_KEY_8, '*'},
    {PS2_SHIFT + PS2_KEY_9, '('},
    {PS2_SHIFT + PS2_KEY_0, ')'},
    {PS2_KEY_KP_DOT, '.'},
    {PS2_KEY_KP_ENTER, PS2_ENTER},
    {PS2_KEY_KP_PLUS, '+'},
    {PS2_KEY_KP_MINUS, '-'},
    {PS2_KEY_KP_TIMES, '*'},
    {PS2_KEY_KP_DIV, '/'},
    {PS2_KEY_KP_COMMA, ','},
    {PS2_KEY_KP_EQUAL, '='},
    {PS2_KEY_APOS, '\''},
    {PS2_SHIFT + PS2_KEY_APOS, '"'},
    {PS2_KEY_COMMA, ','},
    {PS2_SHIFT + PS2_KEY_COMMA, '<'},
    {PS2_KEY_MINUS, '-'},
    {PS2_SHIFT + PS2_KEY_MINUS, '_'},
    {PS2_KEY_DOT, '.'},
    {PS2_SHIFT + PS2_KEY_DOT, '>'},
    {PS2_KEY_DIV, '/'},
    {PS2_SHIFT + PS2_KEY_DIV, '?'},
    {PS2_KEY_SINGLE, '`'},
    {PS2_SHIFT + PS2_KEY_SINGLE, '~'},
    {PS2_KEY_SEMI, ';'},
    {PS2_SHIFT + PS2_KEY_SEMI, ':'},
    {PS2_KEY_BACK, '\\'},
    {PS2_SHIFT + PS2_KEY_BACK, '|'},
    {PS2_KEY_OPEN_SQ, '['},
    {PS2_SHIFT + PS2_KEY_OPEN_SQ, '{'},
    {PS2_KEY_CLOSE_SQ, ']'},
    {PS2_SHIFT + PS2_KEY_CLOSE_SQ, '}'},
    {PS2_KEY_EQUAL, '='},
    {PS2_SHIFT + PS2_KEY_EQUAL, '+'}};

const uint16_t _UKmap[][2] = {
    {PS2_SHIFT + '@', '"'},
    {PS2_SHIFT + '"', '@'},
    {PS2_ALT_GR + '`', PS2_BROKEN_BAR},
    {PS2_SHIFT + '`', PS2_NOT_SIGN},
    {PS2_SHIFT + '#', PS2_POUND_SIGN},
    {'\\', '#'},
    {PS2_SHIFT + '|', '~'},
    {PS2_KEY_EUROPE2, '\\'},
    {PS2_SHIFT + PS2_KEY_EUROPE2, '|'},
};
#ifdef FRENCH
const uint16_t _FRmap[][2] = {
    {'`', PS2_SUPERSCRIPT_TWO},
    {PS2_SHIFT + '~', PS2_SUPERSCRIPT_TWO},
    {'q', 'a'},
    {'Q', 'A'},
    {'1', '&'},
    {PS2_SHIFT + '!', '1'},
    {PS2_ALT_GR + '1', 0},
    {PS2_ALT_GR + PS2_SHIFT + '!', 0},
    {'z', 'w'},
    {'Z', 'W'},
    {'a', 'q'},
    {'A', 'Q'},
    {'w', 'z'},
    {'W', 'Z'},
    {PS2_ALT_GR + '2', '~'},
    {PS2_SHIFT + PS2_ALT_GR + '@', '~'},
    {'2', PS2_e_ACUTE},
    {PS2_SHIFT + '@', '2'},
    {PS2_ALT_GR + '3', PS2_CENT_SIGN},
    {PS2_SHIFT + PS2_ALT_GR + '#', PS2_CENT_SIGN},
    {'3', '"'},
    {PS2_SHIFT + '#', '3'},
    {PS2_ALT_GR + '4', '{'},
    {PS2_SHIFT + PS2_ALT_GR + '$', '{'},
    {'4', '\''},
    {PS2_SHIFT + '$', '4'},
    {PS2_ALT_GR + '5', '['},
    {PS2_SHIFT + PS2_ALT_GR + '%', '['},
    {'5', '('},
    {PS2_SHIFT + '%', '5'},
    {PS2_ALT_GR + '6', '|'},
    {PS2_SHIFT + PS2_ALT_GR + '^', '|'},
    {'6', '-'},
    {PS2_SHIFT + '^', '6'},
    {'m', ','},
    {'M', '?'},
    {PS2_ALT_GR + '7', '`'},
    {PS2_SHIFT + PS2_ALT_GR + '&', '`'},
    {'7', PS2_e_GRAVE},
    {PS2_SHIFT + '&', '7'},
    {PS2_ALT_GR + '8', '\\'},
    {PS2_SHIFT + PS2_ALT_GR + '*', '\\'},
    {'8', '_'},
    {PS2_SHIFT + '*', '8'},
    {',', ';'},
    {PS2_SHIFT + '<', '.'},
    {PS2_ALT_GR + '9', '^'},
    {PS2_SHIFT + PS2_ALT_GR + '(', '^'},
    {'9', PS2_c_CEDILLA},
    {PS2_SHIFT + '(', '9'},
    {PS2_ALT_GR + '0', '@'},
    {PS2_ALT_GR + ')', '@'},
    {'0', PS2_a_GRAVE},
    {PS2_SHIFT + ')', '0'},
    {'.', ':'},
    {PS2_SHIFT + '>', '/'},
    {'/', '!'},
    {PS2_SHIFT + '?', PS2_SECTION_SIGN},
    {';', 'm'},
    {PS2_SHIFT + ':', 'M'},
    {PS2_ALT_GR + '-', ']'},
    {PS2_SHIFT + PS2_ALT_GR + '_', ']'},
    {'-', ')'},
    {PS2_SHIFT + '_', PS2_DEGREE_SIGN},
    {'\'', PS2_u_GRAVE},
    {PS2_SHIFT + '"', '%'},
    {PS2_ALT_GR + '\'', 0},
    {PS2_SHIFT + PS2_ALT_GR + '"', 0},
    {'[', '^'},
    {PS2_SHIFT + '{', PS2_DIAERESIS},
    {PS2_ALT_GR + '=', '}'},
    {PS2_SHIFT + PS2_ALT_GR + '+', '}'},
    {PS2_ALT_GR + ']', PS2_CURRENCY_SIGN},
    {PS2_SHIFT + PS2_ALT_GR + '}', 0},
    {']', '$'},
    {PS2_SHIFT + '}', PS2_POUND_SIGN},
    {'\\', '*'},
    {PS2_SHIFT + '|', PS2_MICRO_SIGN},
    {PS2_SHIFT + PS2_ALT_GR + '|', 0},
    {PS2_ALT_GR + '\\', 0},
    {PS2_KEY_EUROPE2 + PS2_SHIFT + PS2_ALT_GR, '|'},
    {PS2_KEY_EUROPE2 + PS2_ALT_GR, '|'},
    {PS2_SHIFT + PS2_KEY_EUROPE2, '>'},
    {PS2_KEY_EUROPE2, '<'}};
#endif
#ifdef GERMAN
const uint16_t _DEmap[][2] = {
    {'`', '^'},
    {PS2_SHIFT + '~', PS2_DEGREE_SIGN},
    {PS2_ALT_GR + 'q', '@'},
    {PS2_ALT_GR + 'Q', '@'},
    {'y', 'z'},
    {'Y', 'Z'},
    {PS2_ALT_GR + '2', PS2_SUPERSCRIPT_TWO},
    {PS2_SHIFT + PS2_ALT_GR + '@', PS2_SUPERSCRIPT_TWO},
    {PS2_SHIFT + '@', '"'},
    {PS2_ALT_GR + 'e', PS2_CURRENCY_SIGN},
    {PS2_ALT_GR + 'E', PS2_CURRENCY_SIGN},
    {PS2_ALT_GR + '3', PS2_SUPERSCRIPT_THREE},
    {PS2_SHIFT + PS2_ALT_GR + '#', PS2_SUPERSCRIPT_THREE},
    {PS2_SHIFT + '#', PS2_SECTION_SIGN},
    {'z', 'y'},
    {'Z', 'Y'},
    {PS2_SHIFT + '^', '&'},
    {PS2_ALT_GR + 'm', PS2_MICRO_SIGN},
    {PS2_ALT_GR + 'M', PS2_MICRO_SIGN},
    {PS2_SHIFT + '&', '/'},
    {PS2_ALT_GR + '7', '{'},
    {PS2_SHIFT + PS2_ALT_GR + '&', '{'},
    {PS2_SHIFT + '*', '('},
    {PS2_ALT_GR + '8', '['},
    {PS2_SHIFT + PS2_ALT_GR + '*', '['},
    {PS2_SHIFT + '<', ';'},
    {PS2_SHIFT + ')', '='},
    {PS2_ALT_GR + '0', '}'},
    {PS2_SHIFT + PS2_ALT_GR + ')', '}'},
    {PS2_SHIFT + '(', ')'},
    {PS2_ALT_GR + '9', ']'},
    {PS2_SHIFT + PS2_ALT_GR + '(', ']'},
    {PS2_SHIFT + '>', ':'},
    {';', PS2_o_DIAERESIS},
    {PS2_SHIFT + ':', PS2_O_DIAERESIS},
    {PS2_ALT_GR + '-', '\\'},
    {PS2_SHIFT + PS2_ALT_GR + '_', '\\'},
    {'-', PS2_SHARP_S},
    {PS2_SHIFT + '_', '?'},
    {'\'', PS2_a_DIAERESIS},
    {PS2_SHIFT + '"', PS2_A_DIAERESIS},
    {'[', PS2_u_DIAERESIS},
    {PS2_SHIFT + '{', PS2_U_DIAERESIS},
    {'=', '\''},
    {PS2_SHIFT + '+', '`'},
    {']' + PS2_ALT_GR, '~'},
    {PS2_SHIFT + '}' + PS2_ALT_GR, '~'},
    {']', '+'},
    {PS2_SHIFT + '}', '*'},
    {'\\', '#'},
    {PS2_SHIFT + '|', '\''},
    {PS2_KEY_EUROPE2 + PS2_SHIFT + PS2_ALT_GR, '|'},
    {PS2_KEY_EUROPE2 + PS2_ALT_GR, '|'},
    {PS2_SHIFT + PS2_KEY_EUROPE2, '>'},
    {PS2_KEY_EUROPE2, '<'}};
#endif
#ifdef SPANISH
const uint16_t _ESmap[][2] = {
    {PS2_KEY_SINGLE, PS2_MASCULINE_ORDINAL},
    {PS2_SHIFT + PS2_KEY_SINGLE, PS2_FEMININE_ORDINAL},
    {PS2_KEY_SINGLE + PS2_ALT_GR, '\\'},
    {'1' + PS2_ALT_GR, '|'},
    {PS2_SHIFT + '@', '"'},
    {'2' + PS2_ALT_GR, '@'},
    {PS2_SHIFT + '#', PS2_MIDDLE_DOT},
    {'3' + PS2_ALT_GR, '#'},
    {'4' + PS2_ALT_GR, '~'},
    {PS2_SHIFT + '^', '&'},
    {'6' + PS2_ALT_GR, PS2_NOT_SIGN},
    {PS2_SHIFT + '&', '/'},
    {PS2_SHIFT + '*', '('},
    {PS2_SHIFT + '(', ')'},
    {PS2_SHIFT + ')', '='},
    {'-', '\''},
    {PS2_SHIFT + '_', '?'},
    {'=', PS2_INVERTED_EXCLAMATION},
    {PS2_SHIFT + '+', PS2_INVERTED_QUESTION_MARK},
    {'[', '`'},
    {PS2_SHIFT + '{', '^'},
    {'[' + PS2_ALT_GR, '['},
    {']', '+'},
    {PS2_SHIFT + '}', '*'},
    {']' + PS2_ALT_GR, ']'},
    {';', PS2_n_TILDE},
    {PS2_SHIFT + ':', PS2_N_TILDE},
    {'\'', PS2_ACUTE_ACCENT},
    {PS2_SHIFT + '"', PS2_DIAERESIS},
    {'\'' + PS2_ALT_GR, '{'},
    {'\\', PS2_c_CEDILLA},
    {PS2_SHIFT + '|', PS2_C_CEDILLA},
    {'\\' + PS2_ALT_GR, '}'},
    {PS2_SHIFT + PS2_KEY_EUROPE2, '>'},
    {PS2_KEY_EUROPE2, '<'},
    {PS2_SHIFT + '<', ';'},
    {PS2_SHIFT + '>', ':'},
    {PS2_KEY_DIV, '-'},
    {PS2_SHIFT + PS2_KEY_DIV, '+'}};
#endif
#ifdef ITALIAN
const uint16_t _ITmap[][2] = {
    {PS2_KEY_SINGLE, '\\'},
    {PS2_SHIFT + PS2_KEY_SINGLE, '|'},
    {'@', '"'},
    {PS2_SHIFT + '#', PS2_POUND_SIGN},
    {'3' + PS2_ALT_GR, '#'},
    {PS2_SHIFT + '^', '&'},
    {PS2_SHIFT + '&', '/'},
    {'7' + PS2_ALT_GR, '{'},
    {PS2_SHIFT + '*', '('},
    {'8' + PS2_ALT_GR, '['},
    {PS2_SHIFT + '(', ')'},
    {'9' + PS2_ALT_GR, ']'},
    {PS2_SHIFT + ')', '='},
    {'0' + PS2_ALT_GR, '}'},
    {'-', '\''},
    {PS2_SHIFT + '_', '?'},
    {'=', PS2_i_GRAVE},
    {PS2_SHIFT + '+', '^'},
    {'q' + PS2_ALT_GR, '@'},
    {'[', PS2_e_GRAVE},
    {PS2_SHIFT + '{', PS2_e_ACUTE},
    {']', '+'},
    {PS2_SHIFT + '}', '*'},
    {']' + PS2_ALT_GR, '~'},
    {';', PS2_o_GRAVE},
    {PS2_SHIFT + ':', PS2_c_CEDILLA},
    {'\'', PS2_a_GRAVE},
    {PS2_SHIFT + '"', PS2_DEGREE_SIGN},
    {'\\', PS2_u_GRAVE},
    {PS2_SHIFT + '|', PS2_SECTION_SIGN},
    {PS2_SHIFT + PS2_KEY_EUROPE2, '>'},
    {PS2_KEY_EUROPE2, '<'},
    {PS2_SHIFT + '<', ';'},
    {PS2_SHIFT + '>', ':'},
    {PS2_KEY_DIV, '-'},
    {PS2_SHIFT + PS2_KEY_DIV, '+'}};
#endif
#ifdef SPECIAL
const uint16_t _SpecialMap[][2] = {
    // Insert your Special mapping DIFFERENCES from US-ASCII here
};
#endif

// The following structures define the key maps available
typedef struct
{
  char *name;    // 2 Character ISO country code
  uint8_t size;  // Number of entries in map array
  uint16_t *map; // Map array pointer
} PS2Advmap;

// Actual map structure array ( 2 entries for GB and UK for same map
// Because many people don't know ISO code for UK is GB )
const PS2Advmap _KeyMaps[] = {
    {"US", sizeof(_US_ASCII) / (2 * sizeof(uint16_t)), (uint16_t *)_US_ASCII},
#ifdef FRENCH
    {"FR", sizeof(_FRmap) / (2 * sizeof(uint16_t)), (uint16_t *)_FRmap},
#endif
#ifdef GERMAN
    {"DE", sizeof(_DEmap) / (2 * sizeof(uint16_t)), (uint16_t *)_DEmap},
#endif
#ifdef SPANISH
    {"ES", sizeof(_ESmap) / (2 * sizeof(uint16_t)), (uint16_t *)_ESmap},
#endif
#ifdef ITALIAN
    {"IT", sizeof(_ITmap) / (2 * sizeof(uint16_t)), (uint16_t *)_ITmap},
#endif
#ifdef SPECIAL
    {"--", sizeof(_SpecialMap) / (2 * sizeof(uint16_t)), (uint16_t *)_SpecialMap},
#endif
    {"UK", sizeof(_UKmap) / (2 * sizeof(uint16_t)), (uint16_t *)_UKmap},
    {"GB", sizeof(_UKmap) / (2 * sizeof(uint16_t)), (uint16_t *)_UKmap}};

uint8_t _selected_map;

// Private country code strings
const char *_USStr[] = {"US"};

/* Common function to scan a Look up table table and
   return a value or 0 for not found

   Checks using default mask of keycode plus ALT_GR and SHIFT
   To add in match other modifiers set mask to combination of
        PS2_CTRL        match either Control key as well
        PS2_ALT         match left ALT as well
        PS2_GUI         match either GUI key as well

   Assumes map table has 2 dimensions of type prog_uint16_t (in Flash memory)
   i.e. an array like test[ ][ 2 ]
        First entry  (test[][ 0 ]) is item to match
        Second entry (test[][ 1 ]) is item to return

   Parameters are
        data    unsigned int 16 from PS2KeyAdvanced library
        index   index of mapping table to use
*/
uint16_t scan_map(uint16_t data, uint8_t index)
{
  uint16_t idx, result, size;
  uint16_t *maparray;

  // Convert entries count to number of ints
  size = (_KeyMaps[index].size) << 1;
  maparray = (uint16_t *)_KeyMaps[index].map;

  // Leave only required bits for checking against
  result = data & (PS2_ALT_GR + PS2_SHIFT + 0xFF);

  // scan Lookup Table (array) jumping 2 integers at a time
  for (idx = 0; idx < size; idx += 2)
  {
    if (result == *(maparray + idx))
    { // second integer is the replacement value
      result = *(maparray + idx + 1);
      data &= ~0xFF;  // clear old bits retaining CTRL etc
      data |= result; // Make new code
      break;
    }
  }
  return data;
}
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
void loop()
{
  // run pre-set command in auto-mode when PS/2 keyboard is not connected
  // only once after reboot of Keyboard controller
  if (autoMode && !autoCommandSent)
  {
    autoCommandSent = true;
    runAutoModeCommand();
  }

  // check PS2 input
  if (!digitalRead(KEYBOARD_BIT7_PIN) && keyboard.available())
  {
    uint16_t scan_code = keymap.remapKey(keyboard.read());
    uint8_t c = scan_code & 0xff;

    if (scan_code > 0)
    {
      // process Backspace, Left Arrow, Delete as Apple I backspace '_'
      switch (c)
      {
      case PS2_TAB:
      case PS2_KEY_TAB:
        runCommand();
        break;
      case PS2_BACKSPACE:
      case PS2_DELETE:
      case PS2_KEY_L_ARROW:
        c = '_';
        break;
      }
      // make all symbols uppercase (from 'a' (ASCII code 0x61) to 'z' (ASCII code 0x7A))
      // as in original Apple-1
      c = toupper(c);
      // print c to Keyboard Port to be read by CPU
      sendCharToKeyboardPort(c);
    }
  }

  // low-rate clock
  digitalWrite(LORATE_CLOCK_PIN, HIGH);
  digitalWrite(LORATE_CLOCK_LED_PIN, HIGH);
  delay(LORATE_CLOCK_PERIOD_MILLIS); // wait for a LORATE_CLOCK_PERIOD_MILLIS
  digitalWrite(LORATE_CLOCK_PIN, LOW);
  digitalWrite(LORATE_CLOCK_LED_PIN, LOW);
  delay(LORATE_CLOCK_PERIOD_MILLIS); // wait for a LORATE_CLOCK_PERIOD_MILLIS
}

// running pre-set Woz OS command for auto mode
void runAutoModeCommand()
{
  const int cmd_count = 1;
  String cmd1 = String("F000R\r"); // Woz face demo program at $F000
  String commands[] = {cmd1};
  for (int i = 0; i < cmd_count; i++)
    for (int j = 0; j < commands[i].length(); j++)
    {
      char c = commands[i].charAt(j);
      sendCharToKeyboardPort(c);
    }
}
// running pre-set Woz OS command (drawing 8x8 pixel art)
void runCommand()
{
  const int cmd_count = 4;
  String cmd1 = String("1111: 88 A8 50\r");
  String cmd2 = String(":07 61 92\r");
  String cmd3 = String(":94 67\r");
  String cmd4 = String("FC00R\r");
  String commands[] = {cmd1, cmd2, cmd3, cmd4};
  for (int i = 0; i < cmd_count; i++)
    for (int j = 0; j < commands[i].length(); j++)
    {
      char c = commands[i].charAt(j);
      sendCharToKeyboardPort(c);
    }
}

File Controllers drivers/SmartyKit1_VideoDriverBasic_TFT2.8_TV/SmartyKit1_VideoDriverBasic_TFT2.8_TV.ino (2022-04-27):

/*  SmartyKit 1 - 2.8" TFT 320x240 Display module driver with TV output support (TV terminal). v.1.2
 *  http://www.smartykit.io/ 
 *  Copyright (C) 2019, Sergey Panarin <contact@smartykit.io>
 *  
    This program is free software: you can redistribute it and/or modify
    it under the terms of the GNU General Public License as published by
    the Free Software Foundation, either version 3 of the License, or
    (at your option) any later version.
    This program is distributed in the hope that it will be useful,
    but WITHOUT ANY WARRANTY; without even the implied warranty of
    MERCHANTABILITY or FITNESS FOR A PARTICULAR PURPOSE.  See the
    GNU General Public License for more details.
    You should have received a copy of the GNU General Public License
    along with this program.  If not, see <https://www.gnu.org/licenses/>.
*/
#undef _SMARTY_DEBUG_
#include "Smarty_TFT.h"

// Video controller pins connections:
// D0 & D1 – reserved for Serial connection
// D2 -> Beeper (beeps when Video controller has loaded and beeps when char 0x07 (BELL) is received)
// D3 –> 4-16 ports decoder Video (9) out pin (signal is active when CPU writes to Video port)
// D4 -> NC (not connected)
// D5 -> Video BIT7 pin output 
// D6-D13 -> Video port input (8 pins) to connect to Video port (char code is transfered here) 
// A0-A3 -> 2.8" TFT 320x240 Display module connection (SPI bus)
// A4-A5 -> TV terminal via I2C bus (TWI)
#define BEEPER_PIN 2
inline void beep() { tone(BEEPER_PIN, 880, 200); }

#define CPU_WRITESTOVIDEOPORT_PIN 3
#define VIDEO_BIT7_PIN 5

int VideoPort[8] = {6, 7, 8, 9, 10, 11, 12, 13};

// SPI bus connections to Display module
#define TFT_CS -1
#define TFT_RST A0
#define TFT_DC A1
#define TFT_MOSI A2
#define TFT_CLK A3 
#define TFT_MISO -1
//SPI bus: CS is hard-wired to Low (not connected here), RST = A0, DC = A1, MOSI = A2, SCK = A3, MISO = not connected (NC)

//'Made with love by...' string for the splash screen 
char madeWithLoveString[] = "Made with \x03 by Steve Wozniak";

#define TEXT_COLOR ILI9341_CYAN // could be customized from Smarty_TFT.h Color definitions: e.g. ILI9341_NAVY
#define BG_COLOR ILI9341_BLACK   // could be customized from Smarty_TFT.h Color definitions: e.g. ILI9341_DARKGREY


// Woz OS console color scheme
#define CONSOLE_PROMPT_COLOR ILI9341_BLUE
#define CONSOLE_COLON_COLOR ILI9341_MAGENTA //ILI9341_PURPLE
#define CONSOLE_DOT_COLOR ILI9341_OLIVE

#undef _TERMINAL_ //turn off Terminal (TV out)
//#define _TERMINAL_ //turn on Terminal (TV out)

#ifdef _TERMINAL_
  #include <Terminal.h>
  Terminal TV_terminal;   // creating instance of Terminal in I2C (TWI) mode, uses A4 (SDA) and A5 (SCL) as I2C bus
#endif
 

//main code: setup() and loop()
SmartyKit_DisplayDriver Display_module(TFT_CS, TFT_DC, TFT_MOSI, TFT_CLK, TFT_RST, TFT_MISO); //creating instance of our Display Driver
 

void setup() 
{
  Serial.begin(9600);
  Serial.println("setup()");
  pinMode(BEEPER_PIN, OUTPUT);
  pinMode(VIDEO_BIT7_PIN, OUTPUT); 

  DisplayBusy(); //wait until video setup is ready

  // starting TFT screen
  uint16_t color = TEXT_COLOR;
  uint16_t bgColor = BG_COLOR;
  Display_module.setup(color, bgColor, madeWithLoveString);

  beep();

  for (int bit = 0; bit < 8; bit++) {
     pinMode(VideoPort[bit], INPUT); 
  };
  pinMode(CPU_WRITESTOVIDEOPORT_PIN, INPUT_PULLUP);
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

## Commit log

2019-09-08 Keyboard and Video libraries
    Arduino libraries for Keyboard and Video drivers
2019-09-08 Video and Keyboard drivers
    Video and Keyboard drivers
2019-09-08 Keyboard driver
    Keyboard driver
2020-12-19 Schematics of SmartyKit 1
    Schematics of SmartyKit 1 modules connections to help in assembly of the kit.
2021-01-20 SmartyKit 1 ROM asm source & make file
    SmartyKit 1 ROM assembler (asm) source and make file for cc65.
    Easy-to-use development tool to write your own software for SmartyKLit 1 (you need just run make in your Terminal) and learn how ROM is organized.
    [apple1.cfg, symon.cfg]
2021-01-30 ROM version for emulator (without POST tests)
    ROM version that skips Power On Self Test (POST) for using with emulator.
2021-03-14 SmartyKit plate source file for wood laser cutter
    You could use this file for free to produce your own plate for your SmartyKit using wood laser cutter. PCB version (black one) would be available for sale soon.
2021-03-14 Plates – PCB version (black) and Wooden version (laser cut)
    File for wood laser cutter is available for free in this repository.
2021-03-14 Added SmartyKit plate file for wood laser cutter.
2021-03-14 Updated plates image
2021-04-19 SmartyKit schematics in KiCad format
    [SmartyKit_Modules_Scheme.sch]
2021-04-29 Updated Video and Keyboard drivers
    Updated versions of Video and Keyboard drivers (version Jan-2021)
2021-04-29 Remove old drivers
2021-08-28 Keyboard Driver Update to v.1.1 (auto mode, bug fix)
    - auto mode: we added auto mode to send F000R command when PS/2 keyboard is not connected. It could be useful to test Terminal (the first major step) and when SmartyKit 1 is assembled but you don't have PS/2 keyboard available
    - bug fix: we made uppercase not just small caps lettes but all symbols with ASCII codes greater than 0x60. Now we capitalize only 'a' to 'z' (ASCII codes 0x61–0x7A)
    [SmartyKit1_KeyboardDriverBasic.ino]
2022-01-26 Adding PS2KeyAdvanced library to a Keyboard driver to support modern PS/2 Keyboards (like Perixx)
    Adding PS2KeyAdvanced library by Paul Carpenter to let SmartyKit Keyboard controller driver work with modern PS/2 Keyboards (like Perixx – https://youtu.be/6pjx7aud5Eo)
2022-01-30 Beta version of 40 Keys custom keyboard driver
    This driver is used with 40 keys keyboard (10 cols and 4 rows, so 14 pins used) and sends char to CPU via serial connection (3 pins for Clock, Data and Latch).
2022-02-01 Added a fixed PS2KeyMap as SmartyPS2KeyMap
    [SmartyKit1_KeyboardDriverBasic.ino, SmartyKit1_VideoDriverBasic_TFT2.8_TV.ino]
2022-02-04 Removed different connection pins (wiring to Display) for non-TERMINAL mode
2022-02-10 Refactored version of Video driver with support of custom colors & Made by...
    Refactored version of Video driver with support of custom colors & Made with love by...
2022-04-29 SmartyKit assembly picture
2023-03-21 Delete SmartyKit1_40keysKeyboardDriver.ino
    Deleted 40 Keys Keyboard .ino file to remove compilation error in Arduino IDE
2023-04-06 Keyboard Driver Update (Perixx,removed debug code)
2023-04-06 Repo structure update for clarity
    [apple1.cfg, symon.cfg]
2023-10-11 feature: SmartyKit PCB production gerbers
    [SmartyKitPCB-B_Cu.gbl, SmartyKitPCB-B_Mask.gbs, SmartyKitPCB-B_SilkS.gbo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]
2023-10-18 feat: add BOM,CPL files (JLCPCB format), LED part#
    [SmartyKitPCB-BOM.csv, SmartyKitPCB.csv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]
2023-10-18 feat: add SmartyKit PCB preview
2023-10-18 feat: add square SmartyKit PCB preview

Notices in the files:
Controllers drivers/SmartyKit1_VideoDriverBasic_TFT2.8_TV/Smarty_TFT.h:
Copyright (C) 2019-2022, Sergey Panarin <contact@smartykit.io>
